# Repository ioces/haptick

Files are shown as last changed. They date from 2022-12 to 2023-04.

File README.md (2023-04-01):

# Haptick - a 6DOF force sensitive input device

This design is a work in progress and is currently in the proof-of-concept prototyping phase. Progress is being documented via a series of [blog posts](https://blog.ioces.com/matt).

Ultimately the goal is to produce an open source alternative to the various [Spacemice](http://spacemice.org/index.php?title=Main_Page) on the market.

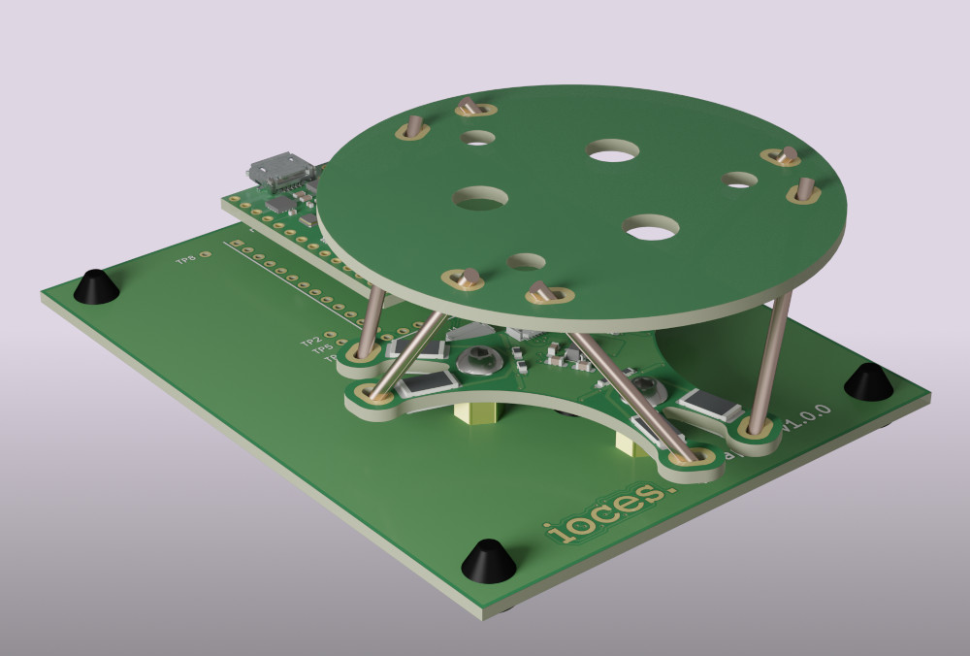
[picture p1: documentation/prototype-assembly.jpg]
Rendering of a prototype Haptick device


## License

This project is licensed under two separate licenses. The hardware design and documentation for this project is licensed under the [CERN Open Hardware Licence Version 2 - Strongly Reciprocal](https://ohwr.org/cern_ohl_s_v2.txt) (CERN-OHL-S-2.0). The software and firmware source code for the project is licensed under the [GNU General Public License Version 3](https://www.gnu.org/licenses/gpl-3.0.txt) (GPL-3.0-only).

Further details can be found in the [license file](LICENSE.md).

### Third Party Libraries

Various third party libraries are used in this project. These libraries are licensed separately from the Haptick project.

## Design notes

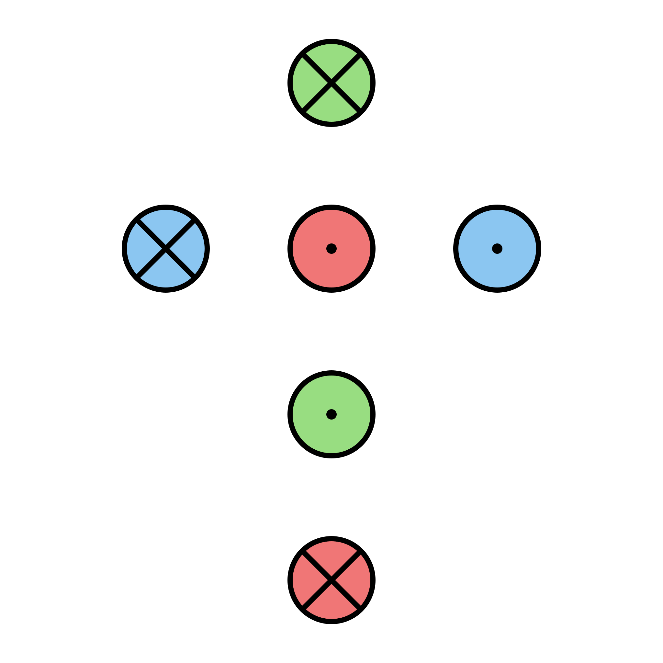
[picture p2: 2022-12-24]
software/utilities/monitor/assets/texture.png

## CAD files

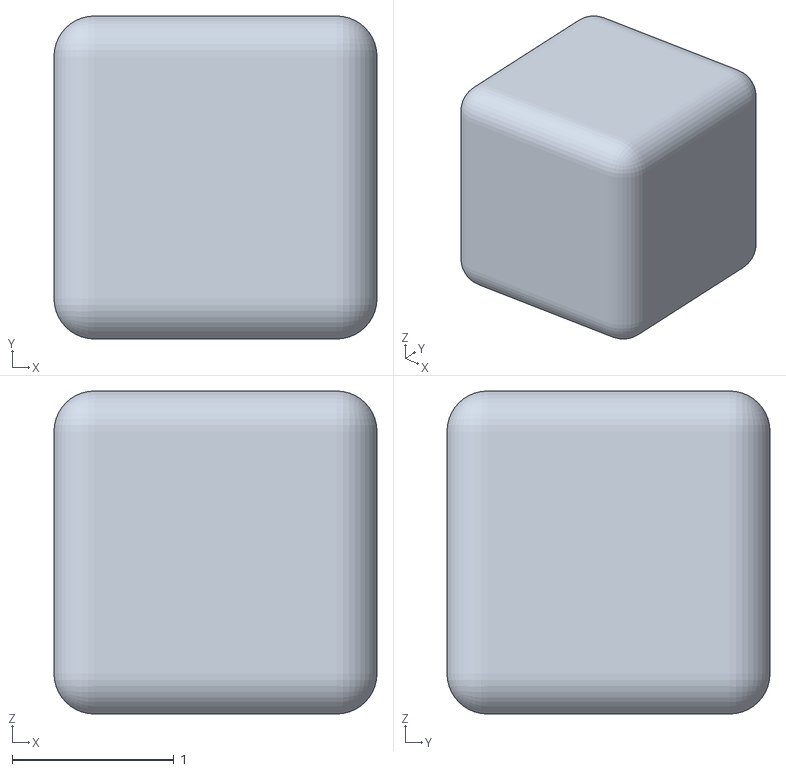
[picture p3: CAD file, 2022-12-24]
software/utilities/monitor/assets/cube.obj
2.00 x 2.00 x 2.00

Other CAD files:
hardware/mechanics/assembly.f3z
hardware/mechanics/slot_solve.f3d
software/utilities/monitor/assets/cube.blend

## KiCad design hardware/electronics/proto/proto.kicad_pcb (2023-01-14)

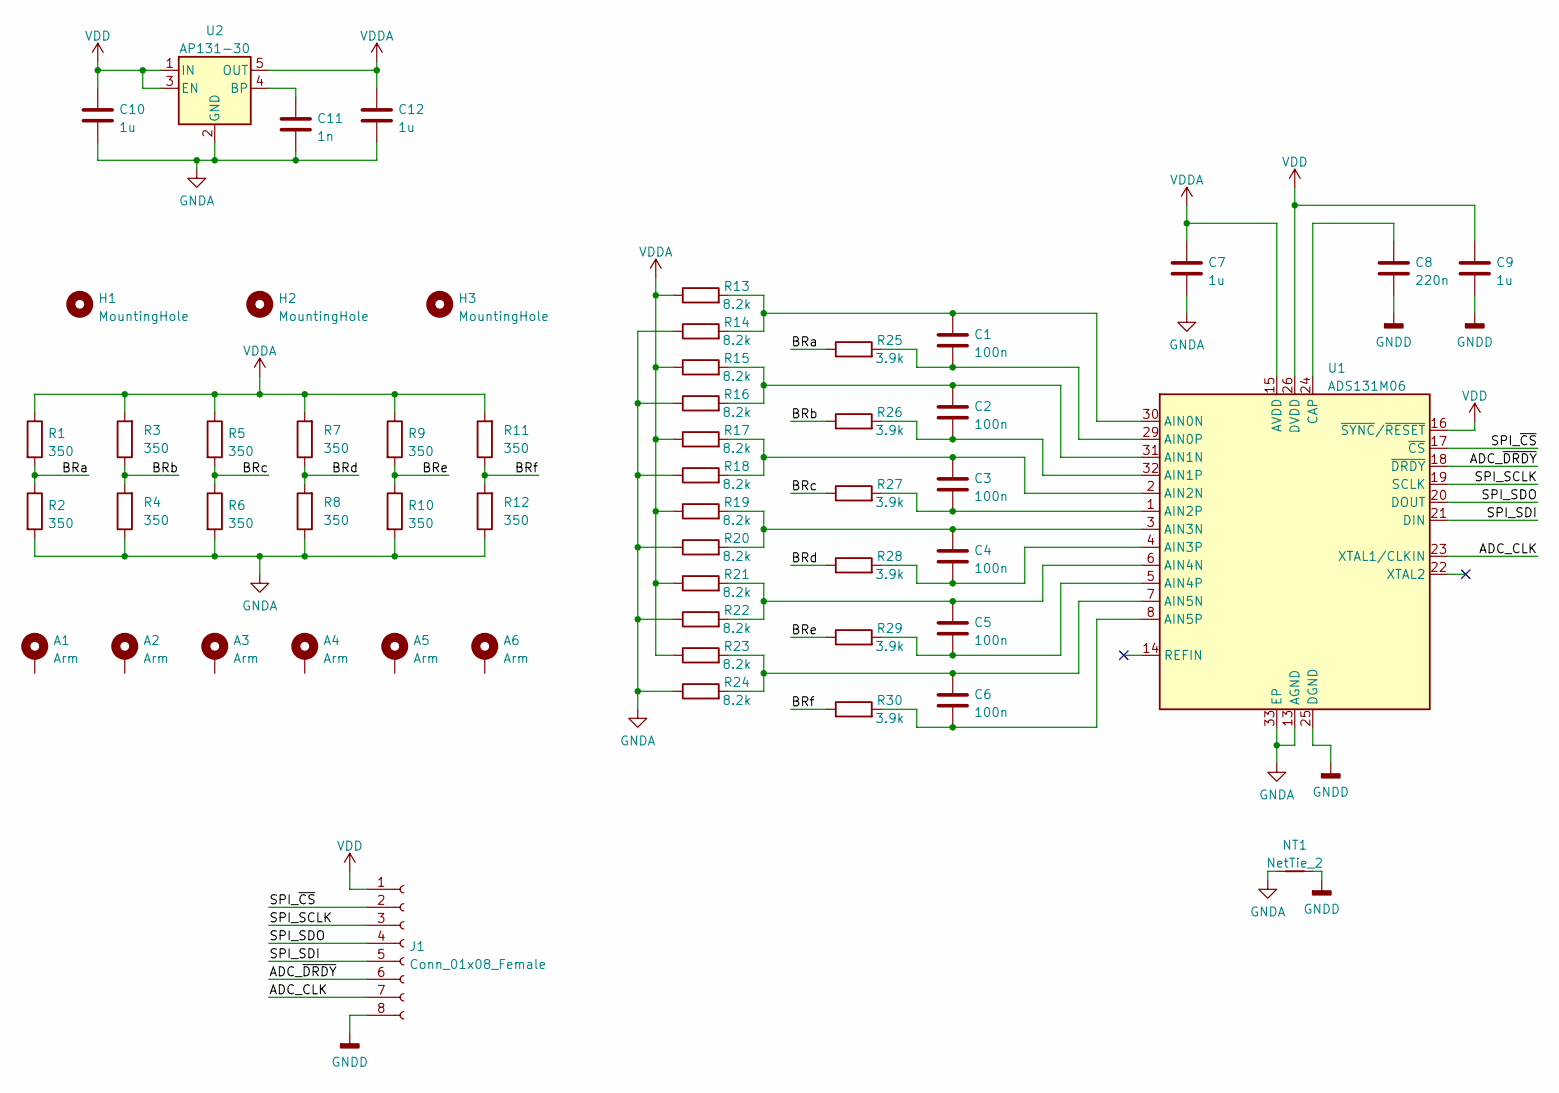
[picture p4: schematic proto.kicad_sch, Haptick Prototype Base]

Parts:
A1, A2, A3, A4, A5, A6: Arm; ArmPad
C1, C2, C3, C4, C5, C6: 100n; C_0603_1608Metric_Pad1.08x0.95mm_HandSolder; Part Number CL10B104KB8WPNC
C7, C9, C10, C12: 1u; C_0603_1608Metric_Pad1.08x0.95mm_HandSolder; Part Number CL10B105KA8NNNL
C8: 220n; C_0603_1608Metric_Pad1.08x0.95mm_HandSolder; Part Number CL10B224KO8NFNC
C11: 1n; C_0603_1608Metric_Pad1.08x0.95mm_HandSolder; Part Number CL10B102KB8WPNC
H1, H2, H3: MountingHole; MountingHole_3.2mm_M3
J1: Conn_01x08_Female; TE_2328702-8_1x08-1MP_P0.5mm_Horizontal; Part Number 2328702-8
NT1: NetTie_2; NetTie-2_SMD_Pad0.2mm
R1, R2, R3, R4, R5, R6, R7, R8, R9, R10, R11, R12: 350; StrainGauge_BF350-3AA; Part Number CRGCQ2512F1K0
R13, R14, R15, R16, R17, R18, R19, R20, R21, R22, R23, R24: 8.2k; R_0603_1608Metric_Pad0.98x0.95mm_HandSolder; Part Number RT0603DRD071KL
R25, R26, R27, R28, R29, R30: 3.9k; R_0603_1608Metric_Pad0.98x0.95mm_HandSolder; Part Number RT0603DRD071KL
U1: ADS131M06; QFN-32-1EP_4x4mm_P0.4mm_EP2.9x2.9mm; Part Number ADS131M06IRSNR
U2: AP131-30; SOT-23-5; Part Number TPS7A2030PDBVR

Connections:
/ADC_CLK: J1.7, U1.23 (XTAL1/CLKIN)
/ADC_~DRDY: J1.6, U1.18 (~DRDY)
/BRa: R1.2, R2.1, R25.1
/BRb: R3.1, R4.2, R26.1
/BRc: R5.2, R6.1, R27.1
/BRd: R7.1, R8.2, R28.1
/BRe: R9.2, R10.1, R29.1
/BRf: R11.1, R12.2, R30.1
/SPI_SCLK: J1.3, U1.19 (SCLK)
/SPI_SDI: J1.5, U1.21 (DIN)
/SPI_SDO: J1.4, U1.20 (DOUT)
/SPI_~CS: J1.2, U1.17 (~CS)
GNDA: C7.2, C10.2, C11.2, C12.2, NT1.1, R2.2, R4.1, R6.2, R8.1, R10.2, R12.1, R14.1, R16.1, R18.1, R20.1, R22.1, R24.1, U1.13 (AGND), U1.28 (AGND), U1.33 (EP), U2.2 (GND)
GNDD: C8.2, C9.2, J1.8, NT1.2, U1.25 (DGND)
unnamed: C1.1, R13.2, R14.2, U1.30 (AIN0N)
unnamed: C1.2, R25.2, U1.29 (AIN0P)
unnamed: C2.1, R15.2, R16.2, U1.31 (AIN1N)
unnamed: C2.2, R26.2, U1.32 (AIN1P)
unnamed: C3.1, R17.2, R18.2, U1.2 (AIN2N)
unnamed: C3.2, R27.2, U1.1 (AIN2P)
unnamed: C4.1, R19.2, R20.2, U1.3 (AIN3N)
unnamed: C4.2, R28.2, U1.4 (AIN3P)
unnamed: C5.1, R21.2, R22.2, U1.6 (AIN4N)
unnamed: C5.2, R29.2, U1.5 (AIN4P)
unnamed: C6.1, R23.2, R24.2, U1.7 (AIN5N)
unnamed: C6.2, R30.2, U1.8 (AIN5P)
unnamed: C8.1, U1.24 (CAP)
unnamed: C11.1, U2.4 (BP)
VDD: C9.1, C10.1, J1.1, U1.16 (~SYNC/~RESET), U1.26 (DVDD), U2.1 (IN), U2.3 (EN)
VDDA: C7.1, C12.1, R1.1, R3.2, R5.1, R7.2, R9.1, R11.2, R13.1, R15.1, R17.1, R19.1, R21.1, R23.1, U1.15 (AVDD), U2.5 (OUT)

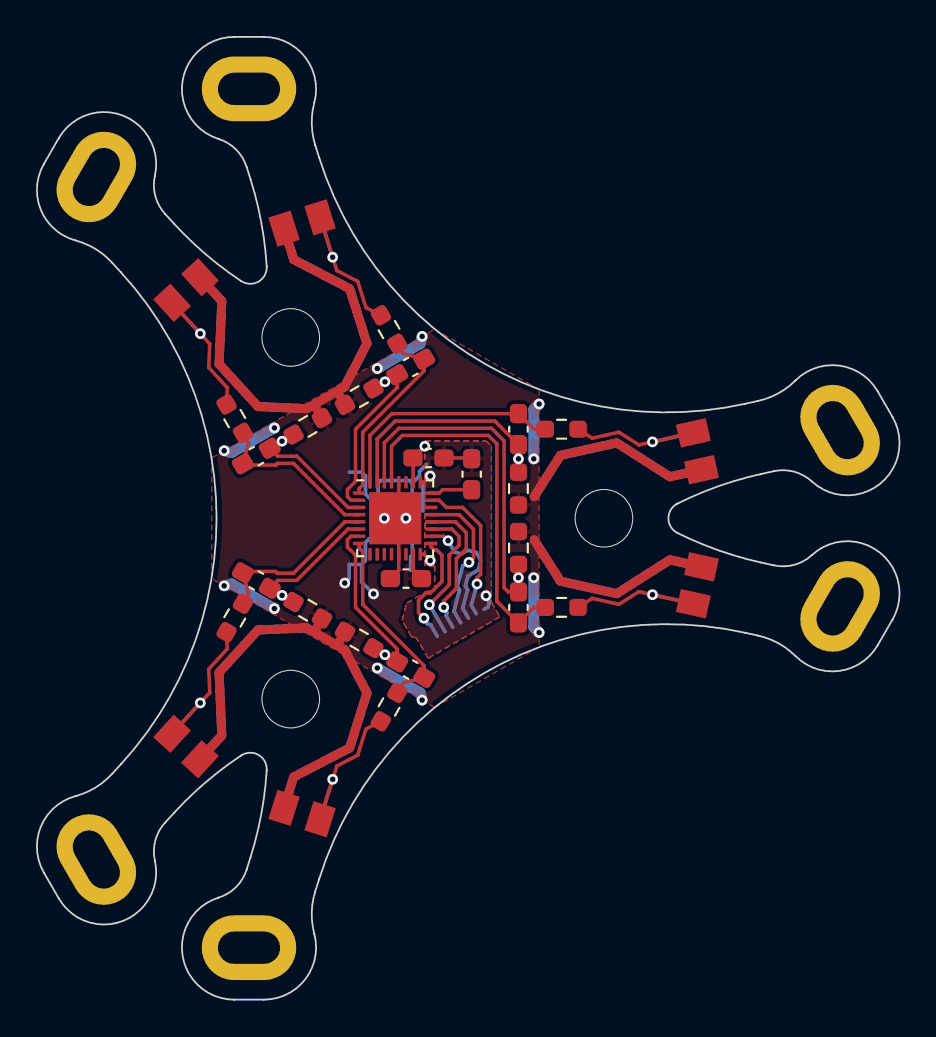
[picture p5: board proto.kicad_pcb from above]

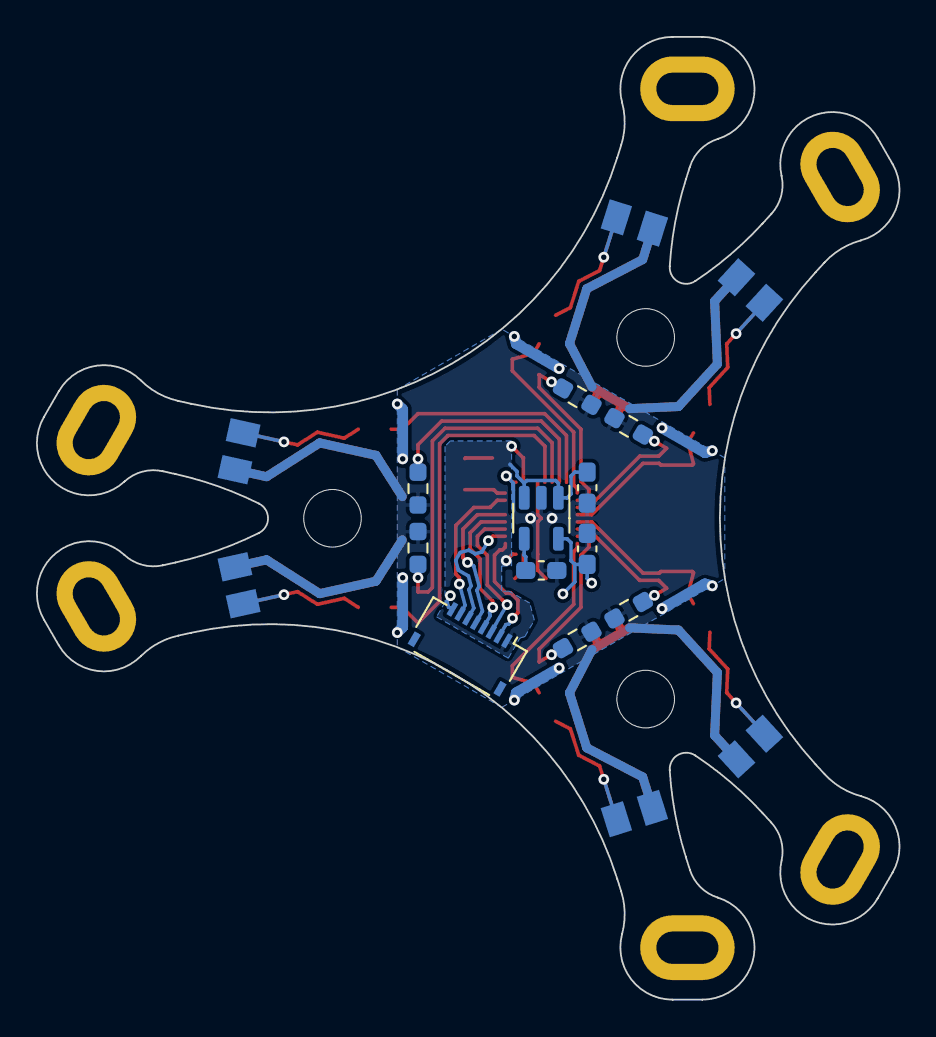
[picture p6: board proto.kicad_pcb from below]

Board: 2 copper layers, 47.9 x 53.5 mm, 55 parts (21 on the bottom side), 30 nets.

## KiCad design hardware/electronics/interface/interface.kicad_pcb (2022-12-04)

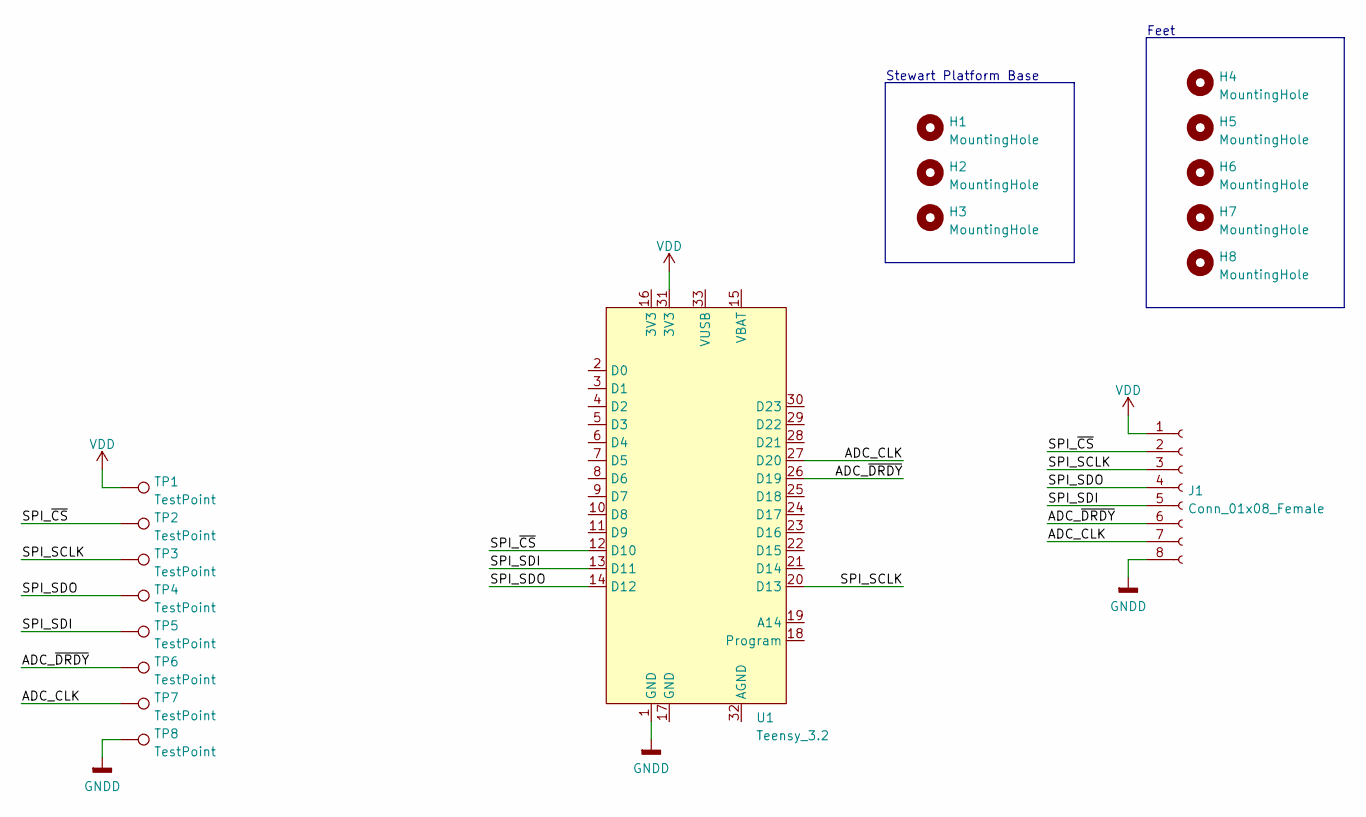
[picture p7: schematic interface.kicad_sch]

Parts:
H1, H2, H3: MountingHole; MountingHole_PEM_M3_Broaching_Nut
H4, H5, H6, H7, H8: MountingHole; MountingHole_4.5mm
J1: Conn_01x08_Female; TE_2328702-8_1x08-1MP_P0.5mm_Horizontal
TP1, TP2, TP3, TP4, TP5, TP6, TP7, TP8: TestPoint; TestPoint_THTPad_D1.6mm_Drill0.9mm
U1: Teensy_3.2

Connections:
/ADC_CLK: J1.7, TP7.1, U1.27 (D20)
/ADC_~DRDY: J1.6, TP6.1, U1.26 (D19)
/SPI_SCLK: J1.3, TP3.1, U1.20 (D13)
/SPI_SDI: J1.5, TP5.1, U1.13 (D11)
/SPI_SDO: J1.4, TP4.1, U1.14 (D12)
/SPI_~CS: J1.2, TP2.1, U1.12 (D10)
GNDD: J1.8, TP8.1, U1.1 (GND)
VDD: J1.1, TP1.1, U1.31 (3V3)

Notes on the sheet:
Feet
Stewart Platform Base

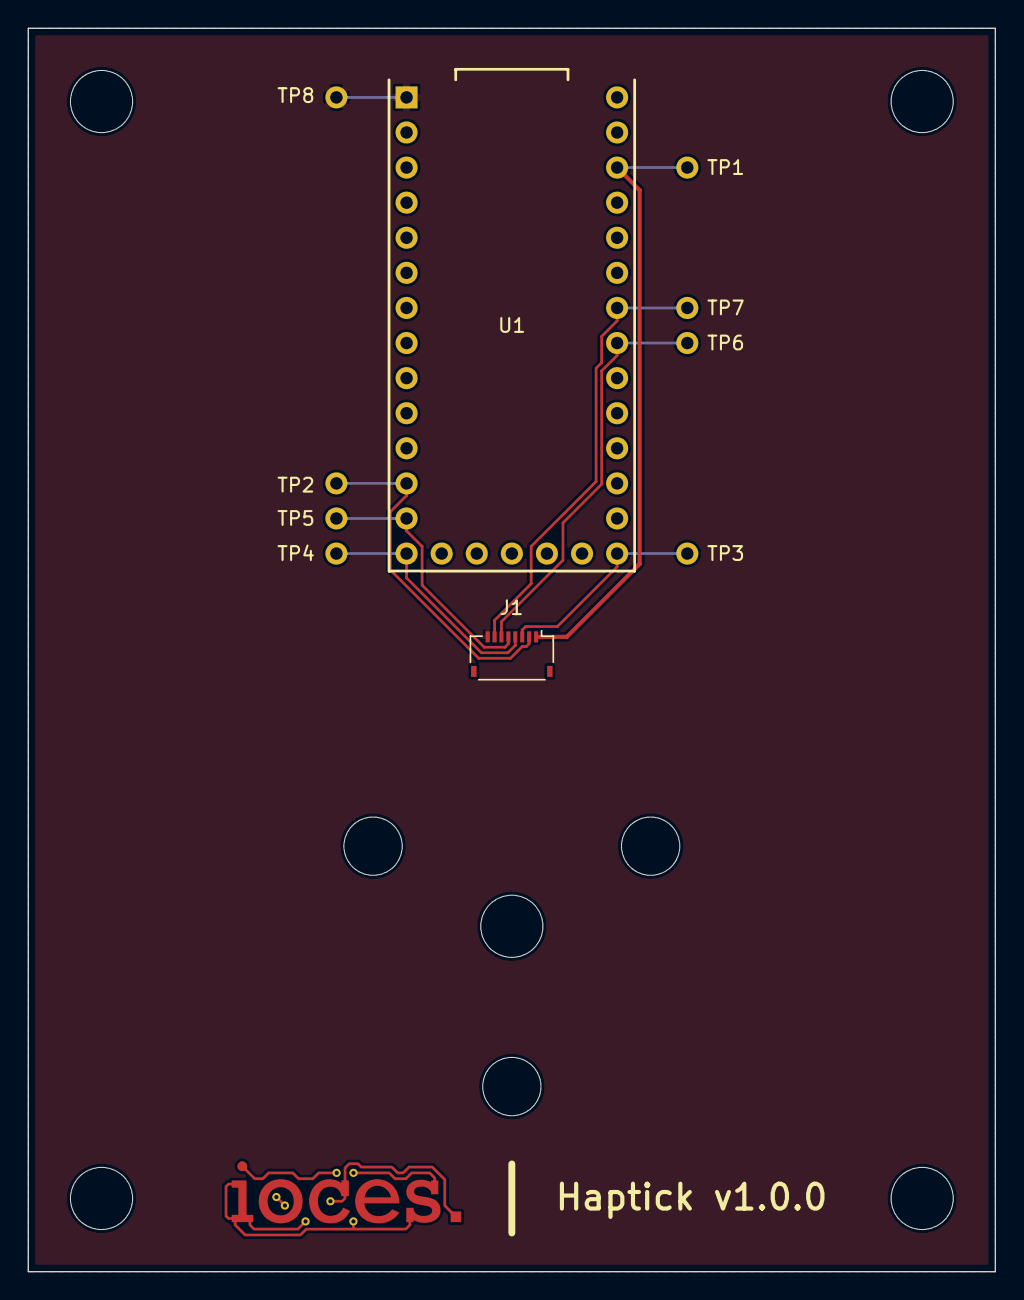
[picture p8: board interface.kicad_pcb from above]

Board: 2 copper layers, 70.0 x 90.0 mm, 19 parts (0 on the bottom side), 8 nets.

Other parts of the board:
Ref**: Val**; IocesLogo

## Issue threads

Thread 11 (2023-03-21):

Some thoughts about strain gauges.

troisiemetype, 2023-03-21:
Hello,

I've just read the article on Hackaday and on your blog, and it brings me two thoughts :

1. I believe the red-dotted trackpad on Thinkpads uses strain jauges too. I was surprised to see that once you've removed the rubber part and the plastic part beneath it, you're left with rigid metallic component, with zero degrees of freedom.
2. The idea of using resistors for strain gauges is brilliant. I wonder if that could be pushed further, by directly using specifically designed tracks as strain gauges ?

Thank you for this complete writing on your research !

m-schubert, 2023-03-21:
Thanks for getting in touch @troisiemetype.

1. Yeah, I'm not surprised the Thinkpad [nub](https://xkcd.com/243/) uses strain gauges. It only has 2 degrees of freedom, so you could get away with a pretty simple load cell design to implement it.
2. I considered trying to etch the gauges directly onto the PCB. Actually, the folks at Duet 3D used to use thick film resistors like I did for their [Smart Effector](https://www.duet3d.com/DeltaSmartEffector), but have moved to PCB traces. The problem I see is they're going to be really low impedance. With 17.5 um copper and 0.1 mm traces, I only get several ohms of impedance in the strain sensitive area. That's too low to excite directly with a voltage source and digitise directly with an ADC. I have seen some constantin foil, or direct resistive element on PCB technology that could be worth a shot.

troisiemetype, 2023-03-22:
I didn't think of the low impedance of the tracks. But another problem may be the tolerances of the PCB manufacturer. I suppose they are far less than on a strain gauge, which may imply a more complex calibration procedure.

m-schubert, 2023-03-26:
Yeah, generally I see pretty high resolution traces on the foil strain gauges - certainly higher than most PCB manufacturers will hit. It's something I might investigate in the future, but for now I'll begrudgingly glue strain gauges to the PCBs.

I'll close this "issue" as resolved. Thanks again for getting in touch!

Closed 2023-03-26.

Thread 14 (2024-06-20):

updates/bom?

infowolfe, 2024-06-20:
At the moment the "part 2" blog post links to a bom that's missing and says you'd be continuing work on this project. Any chance that's still in the cards? It'd be really interesting to buy/build a haptick.

m-schubert, 2024-06-20:
Hi @infowolfe, you're right about the interactive BOM, sorry about that. I'll get it fixed tonight.

Regarding an update - I have built the version with the strain gauges (it's currently the design found in `main` in this repo), but it totally didn't work like I'd hoped. It looks like the copper trusses are introducing significant torques on the arms and the solution to the Stewart platform isn't solvable or calibrateable.

The good news is that I have some more ideas to test, but haven't yet gotten around to it. Sorry about the slow update rate.

I'll leave this issue open to try and motivate me to sort out an update :)

infowolfe, 2024-06-20:
@m-schubert thanks for the update, I guess I'll just suffer under 3dconn's completely broken drivers when it comes to both MacOS Ventura (prefPane doesn't load or loads empty) and their insanity when it comes to needing to literally invert EVERY axis for shapr3d to work in an intuitive way.

Honestly the fact that they're the only company doing a 6dof controller for CAD in 2024 is wild to me.

m-schubert, 2024-06-20:
Interactive BOM should now be working on the site.

Yeah, 3Dconnexion has purchased a crazy amount of patents and has basically captured the market via them. There are some other open source attempts, including some that look more successful than mine at the moment:
https://github.com/pepijndevos/spacefox
https://hackaday.io/project/187172-os3m-mouse
https://www.youtube.com/watch?v=2xAk-wegS9o

ruevs, 2025-03-18:
> It looks like the copper trusses are introducing significant torques on the arms and the solution to the Stewart platform isn't solvable or calibrateable.

@infowolfe When I read your [part two](https://blog.ioces.com/matt/posts/haptick-part-two/) blog post I thought that since with your approach the displacements are minimal a good approximation of stiff rods with ball joints would be thin stainless steel tubes (e.g. 1mm diameter - injection needles) with very thin copper wires running through them - pulled tight and soldered to the boards at both ends. The tube will transmit the compression and the wire the tension forces and both ends will be fairly free to pivot.

The copper wire will probably eventually break but it will be an interesting test - and should be very easy to retrofit in your test device.

m-schubert, 2025-03-18:
@ruevs, funny you should say that. I had some similar ideas when I hit the hurdle, and ended up making the trusses out of string, with tension springs in the middle to keep them in tension. It works great! I ran some calibrations and it's very close to a linear system.

Teaser photo:

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

I'll try and get an update on the blog soon.

ruevs, 2025-03-19:
> trusses out of string, with tension springs in the middle to keep them in tension. It works great! I ran some calibrations and it's very close to a linear system.

This is a great idea - should have much less hysteresis (better return to origin) than the solution I proposed and your original one. And you have (of course :-) glued the string in the holes so that it does not slip.

You [mentioned](https://github.com/ioces/haptick/issues/14#issuecomment-2181079862) that you built the version with the strain gauges. Did it improve the sensitivity (signal to noise ratio) enough to allow reliable detection of whether the user is holding the knob and re-zeroing based on that?

Your project (and the "[OS3M Mouse](https://hackaday.io/project/187172-os3m-mouse)") looks really promising and is the first open hardware project that I am seriously tempted to build in a long time - SpaceMice [have become](https://github.com/ruevs/libspnavdev?tab=readme-ov-file#history) a bit of a [hobby](https://github.com/FreeSpacenav/libspnavdev/pull/4#issuecomment-1907781102) for me :-)

m-schubert, 2025-03-20:
The "inversion function/matrix" will not be the same as for a Stewart platform since there will be no compression (downward on the strain gauges) forces but I can not (not in my head, probably not even on paper :-) figure out if it will still hold enough information to decouple the 6DOFs. If [your calibrations](https://github.com/m-schubert/haptick/commit/0f4350f5a83c8e6c73702f7564105ddda45007ba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) worked it would mean that it does?

It works. I haven't checked to see how closely it matches an ideal Stewart platform, but I have validated the linearity by applying a pure force, and a force with a torque in each direction. Adding the force/torque combos together causes the torque components to cancel, and I do end up with something that within a few percent of a pure force reaction. The error is likely due to some small impact of the springs and maybe some torques transmitted through the string.

> You [mentioned](https://github.com/ioces/haptick/issues/14#issuecomment-2181079862) that you built the version with the strain gauges. Did it improve the sensitivity (signal to noise ratio) enough to allow reliable detection of whether the user is holding the knob and re-zeroing based on that?

I did assemble a device with pure strain gauges, and I did verify they're substantially more sensitive. I got some totally insane results with the copper trusses, though. Pushing down on the platform actually resulted in a response in the exact opposite direction. I think the strain gauges are also more sensitive to twisting of the arms.

I haven't yet tried a string/spring combo with strain gauges yet, but I might give it a go after I get a blog post up. I have some much better ideas for a "production" ready device which I'll probably work on in the future, too.

> Your project (and the "[OS3M Mouse](https://hackaday.io/project/187172-os3m-mouse)") looks really promising and is the first open hardware project that I am seriously tempted to build in a long time - SpaceMice [have become](https://github.com/ruevs/libspnavdev?tab=readme-ov-file#history) a bit of a [hobby](https://github.com/FreeSpacenav/libspnavdev/pull/4#issuecomment-1907781102) for me :-)

If you're interested in a bit of a collab, I'm happy to get some better hardware out if you're interested in writing some code for drivers and the like.

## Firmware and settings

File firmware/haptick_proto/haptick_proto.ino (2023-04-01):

#include <SPI.h>

const int adc_clk_pin = 20;
const int adc_ndrdy_pin = 19;
const int spi_ncs_pin = 10;

// SPI settings
const SPISettings spi_settings(8000000, MSBFIRST, SPI_MODE1);

bool buffer_empty = true;
char adc_buffer[24];

void adc_data_ready() 
{
  // If we've sent the last set of results, grab new ones into the buffer
  if (buffer_empty)
  {
    SPI.beginTransaction(spi_settings);
    digitalWrite(spi_ncs_pin, LOW);
    SPI.transfer(adc_buffer, 24);
    digitalWrite(spi_ncs_pin, HIGH);
    SPI.endTransaction();
    buffer_empty = false;
  }
}

void setup()
{
  // Create an 8 MHz 50% duty cycle clock for the ADC
  // This requires overclocking the Teensy to 96 MHz to
  // get a 48 MHz PWM clock, which is then divided by 6
  // to get the 8 MHz clock.
  //
  // It puts us in a weird situation where the PWM counter
  // can range from 0 - 5, which doesn't nicely map to the
  // 0 - 255 range for the analogWrite() call. But the below
  // code seems to work.                
  pinMode(adc_clk_pin, OUTPUT);
  analogWriteFrequency(adc_clk_pin, 8000000);
  analogWrite(adc_clk_pin, 128);

  // Delay for a bit to make sure the ADC is alive
  delay(100);

  // Start SPI and pull !CS high
  SPI.begin();
  pinMode(spi_ncs_pin, OUTPUT);
  digitalWrite(spi_ncs_pin, HIGH);

  // Configure the ADC to use an oversampling rate of 1024,
  // and PGA gains of 64
  uint16_t clock_register = 0x3f0e;
  SPI.beginTransaction(spi_settings);
  digitalWrite(spi_ncs_pin, LOW);
  SPI.transfer16(0x6182);
  SPI.transfer(0);
  SPI.transfer16(clock_register);
  SPI.transfer(0);
  SPI.transfer16(0x6666);
  SPI.transfer(0);
  SPI.transfer16(0x0066);
  SPI.transfer(0);
  SPI.transfer16(0);
  SPI.transfer(0);
  digitalWrite(spi_ncs_pin, HIGH);
  SPI.endTransaction();

  // Wait for serial to come up
  while (!Serial);

  // Set up an interrupt on the ADC_!DRDY pin
  attachInterrupt(digitalPinToInterrupt(adc_ndrdy_pin), adc_data_ready, FALLING);
}

void loop()                     
{
  // Dump values out the serial port every time new readings come in
  if (!buffer_empty)
  {
    Serial.write(adc_buffer, 24);
    memset(adc_buffer, 0, 24);
    buffer_empty = true;
  }
}

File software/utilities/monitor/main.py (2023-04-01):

import sys
from PySide6.QtCore import QTimer
from PySide6.QtGui import QIcon
from PySide6.QtWidgets import QApplication, QMainWindow, QFileDialog
from ui_mainwindow import Ui_MainWindow
import time
import interface
import numpy as np


class MainWindow(QMainWindow):
    def __init__(self):
        super(MainWindow, self).__init__()
        self.ui = Ui_MainWindow()
        self.ui.setupUi(self)
        self.haptick = interface.Haptick()
    
        self.ui.serialPortCombo.addItems(self.haptick.list_ports())
        self.ui.serialConnectButton.clicked.connect(self._connect)

        self.ui.recordButton.toggled.connect(self._start_record)

        self.ui.filterCutoffSlider.valueChanged.connect(self._change_filter_cutoff)
        self._change_filter_cutoff(self.ui.filterCutoffSlider.value())

        self.ui.biasGroupBox.clicked.connect(self._change_bias_correction)
        self.ui.biasThresholdSlider.valueChanged.connect(self._change_bias_correction)
        self.ui.biasTimeSlider.valueChanged.connect(self._change_bias_correction)
        self._change_bias_correction()

        self.update_timer = QTimer(self)
        self.update_timer.setInterval(20)
        self.update_timer.timeout.connect(self._update)

        self.__file = None
    
    def closeEvent(self, event):
        super().closeEvent(event)
        if self.__file:
            self._stop_record()
        self.update_timer.stop()
        self.haptick.disconnect()

    def _connect(self):
        self.haptick.connect(self.ui.serialPortCombo.currentText())
        self.update_timer.start()
        self.ui.serialPortCombo.setDisabled(True)
        self.ui.serialConnectButton.setText("Disconnect")
        self.ui.serialConnectButton.setIcon(QIcon(":/icons/disconnect"))
        self.ui.serialConnectButton.clicked.disconnect(self._connect)
        self.ui.serialConnectButton.clicked.connect(self._disconnect)
    
    def _disconnect(self):
        self.update_timer.stop()
        self.haptick.disconnect()
        self.ui.serialPortCombo.setDisabled(False)
        self.ui.serialConnectButton.setText("Connect")
        self.ui.serialConnectButton.setIcon(QIcon(":/icons/connect"))
        self.ui.serialConnectButton.clicked.disconnect(self._disconnect)
        self.ui.serialConnectButton.clicked.connect(self._connect)
    
    def _start_record(self):
        # Temporarily stop the update timer while we get a filename and start
        # recording. There are two reasons for this:
        #
        # 1. With the 20ms timer, some bug in Qt means the save file dialog
        #    doesn't display, as the event loop spends all its time serving the
        #    timer.
        # 2. We want to start saving data from when the record button is hit. If
        #    we stop the timer, the interprocess queue will start to buffer all
        #    samples from when the timer is stopped, which means they'll all get
        #    written to disk when the timer starts again.
        timer_active = self.update_timer.isActive()
        self.update_timer.stop()

        # Get a filename and update the button state.
        file_name, _ = QFileDialog.getSaveFileName(self, "Record File", "", "Comma Separated Values (*.csv)")

        if file_name:
            self.__file = open(file_name, 'w')
            self.ui.recordButton.toggled.disconnect(self._start_record)
            self.ui.recordButton.toggled.connect(self._stop_record)
        else:
            # Temporarily block signals, change checked state and unblock. Else
            # we get called again when we try and uncheck the button.
            self.ui.recordButton.blockSignals(True)
            self.ui.recordButton.setChecked(False)
            self.ui.recordButton.blockSignals(False)
        
        # Start the timer again.
        if timer_active:
            self.update_timer.start()
    
    def _stop_record(self):
        self.__file.close()
        self.__file = None
        self.ui.recordButton.toggled.disconnect(self._stop_record)
        self.ui.recordButton.toggled.connect(self._start_record)
        self.ui.recordButton.setIcon(QIcon(":/icons/record"))
    
    def _update(self):
        vals = self.haptick.get_vals()

        if vals is not None:
            self.ui.voltagePlot.add_values(vals)
            self.ui.psdPlot.add_values(vals)
            self.ui.noiseWidget.add_values(vals)
            self.ui.cubeControl.add_values(vals)
            
            if self.__file:
                np.savetxt(self.__file, vals, fmt="%.3e", delimiter=",")
        
        if self.ui.recordButton.isChecked():
            if time.monotonic() % 1 > 0.5:
                self.ui.recordButton.setIcon(QIcon(":/icons/blank"))
            else:
                self.ui.recordButton.setIcon(QIcon(":/icons/record"))
    
    def _change_filter_cutoff(self, value):
        if value == 99:
            self.haptick.filter_cutoff = None
            self.ui.filterCutoffValue.setText("Disabled")
        else:
            frequency = 10 ** (value * 4.29 / 98 - 1)
            self.haptick.filter_cutoff = frequency
            self.ui.filterCutoffValue.setText(f"{frequency:.1f} Hz")
    
    def _change_bias_correction(self, *_):
        time = self.ui.biasTimeSlider.value() / 99.0 * 3.0 + 1.0
        threshold = self.ui.biasThresholdSlider.value() / 99.0 * 2.0e-6
        enabled = self.ui.biasGroupBox.isChecked()

        settings = interface.BiasCorrectionSettings(enabled, threshold, time)
        self.haptick.bias_correction = settings


if __name__ == "__main__":
    app = QApplication(sys.argv)

    window = MainWindow()
    window.show()

    sys.exit(app.exec())

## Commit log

2022-12-10 Add a power spectral density plot (#1)
2022-12-11 Add a widget displaying RMS noise of the 6 channels (#3)
    [main.py, visualisers.py]
2022-12-24 Calculate and display position/rotation from input forces and torques (#4)
    [cube.blend, cube.obj]
2022-12-26 Improve reliability of the prototype serial connection (#2)
2023-01-12 Use strain gauges instead of thick film resistors (#8)
    [proto.kicad_pcb, proto.kicad_sch]
2023-01-13 Prepare for release of new prototype (#9)
    [proto.kicad_pcb, proto.kicad_sch]
2023-01-14 Rebuild zones and generate Gerbers for prototype base
    [proto.kicad_pcb]
2023-02-25 Update manufacturers and part numbers for new prototype (#10)
    [proto.kicad_sch]
2023-04-01 Delay startup of SPI and configuration setting (#13)
    This is necessary on the latest prototype. I think the ADC is taking a little while to come up, and is missing the configuration sent to it without the delay.
    [haptick_proto.ino]
